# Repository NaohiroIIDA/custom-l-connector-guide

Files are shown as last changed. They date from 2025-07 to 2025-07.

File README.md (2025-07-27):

# ホットボンド成形によるL字コネクタ加工ガイド

このリポジトリは、汎用のコネクタをホットボンドと金型でL字加工する手順と、そのためのアルミ金型を低価格で外注する方法をまとめたものです。

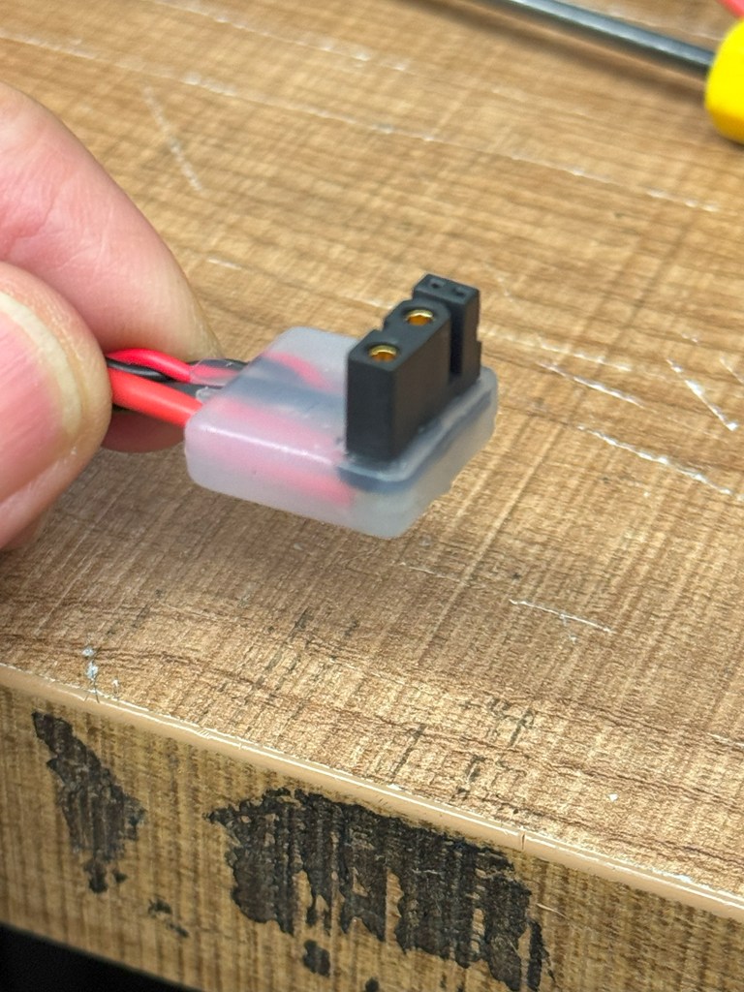
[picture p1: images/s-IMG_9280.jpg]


## 🔧 目的

ロボットや電子回路のケーブル配線において、コネクタの向きをモータに沿わせたい場面は多々あります。  
本ガイドでは、誰でも簡単に、安価に、L字のコネクタ加工ができるようにノウハウを共有します。

---

## 📦 内容一覧

- `mold-design/` : アルミ金型の設計図（PDF・CAD）
- `jlccnc-order-guide.md` : JLCCNCで金型を発注する方法
- `connector-molding.md` : 実際のL字加工手順
- `parts-list.md` : 使用部材・工具一覧
- `images/` : 各工程の写真・完成例

---

## 🌎 金型発注先について

金型は中国のCNC加工サービス「JLCCNC（[https://jlccnc.com](https://jlccnc.com)）」を利用しました。  
アルミ製の簡易金型で、1個あたり約\$38。発注から6日で到着しました。

詳細な発注手順は [`jlccnc-order-guide.md`](jlccnc-order-guide.md) をご覧ください。

---

## ✋ 注意事項

- 本ガイドはDIY用途を想定しています。高電圧・高周波用途のコネクタには使用しないでください。
- 加熱器具やホットボンド使用時は火傷にご注意ください。

---

## 📄 ライセンス

このリポジトリの内容は [CC BY 4.0](https://creativecommons.org/licenses/by/4.0/deed.ja) に基づき公開しています。

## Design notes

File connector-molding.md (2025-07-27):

# L字コネクタ加工の手順（ホットボンド成形）

このファイルでは、JLCCNCで製作したアルミ金型を用いて、USBやピンヘッダなどの汎用コネクタをホットボンド樹脂でL字に成形する手順を解説します。

---

## 🧰 使用するもの

| 品名 | 備考 |
|---|---|
| アルミ金型（上下2ピース） | JLCCNCで発注 |
| 加工したいコネクタ | 例：XT30(2+2),USBなど |
| ホットボンドガン（スティック） | 高温タイプ推奨 |
| ネジ・クランプ等 | 金型固定用 |
| 耐熱手袋 | 安全対策に |
| ニッパー、カッターなど | 成形後のバリ処理用 |

---

## 🛠 加工手順

### 1. 金型の準備
- 金型をきれいに拭き取り、内部に残ったホコリや異物を取り除く
- 必要に応じて、シリコンスプレーなどで軽く離型処理を行う

### 2. コネクタの設置
- コネクタの端子やケーブルを曲げ、L字の形に合わせて金型内に設置する
- 端子がずれないように注意し、必要なら仮止めテープなどを使用する

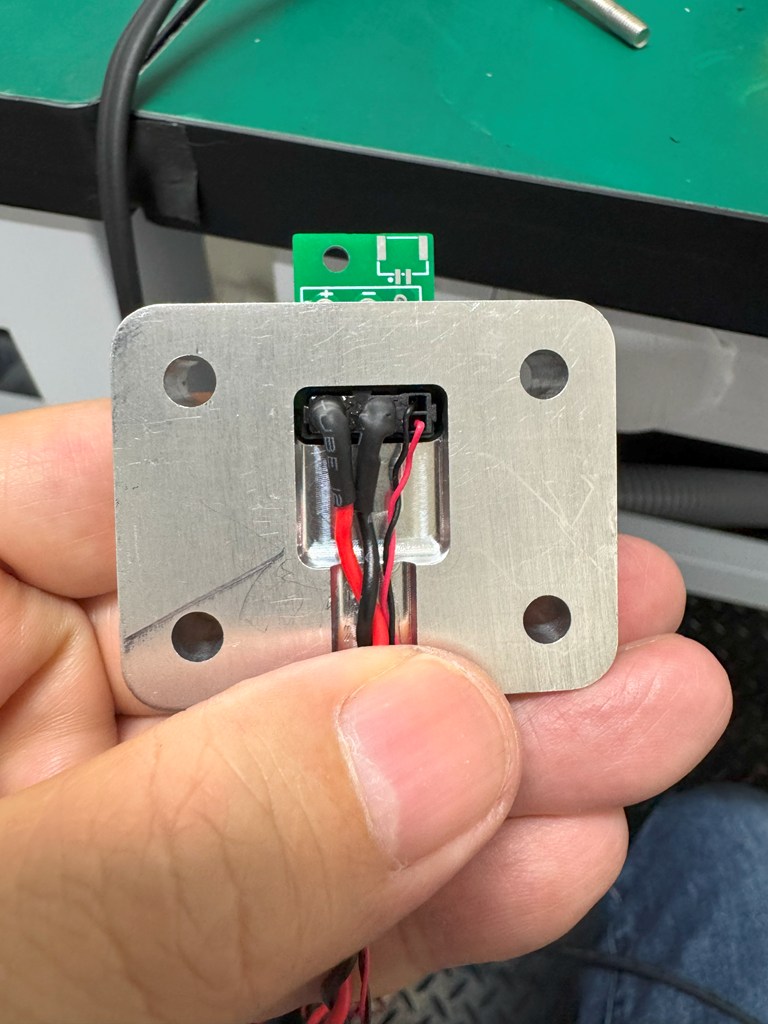
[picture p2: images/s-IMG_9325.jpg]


### 3. 金型の固定
- 上下の金型を合わせ、ネジやクランプでしっかりと固定する

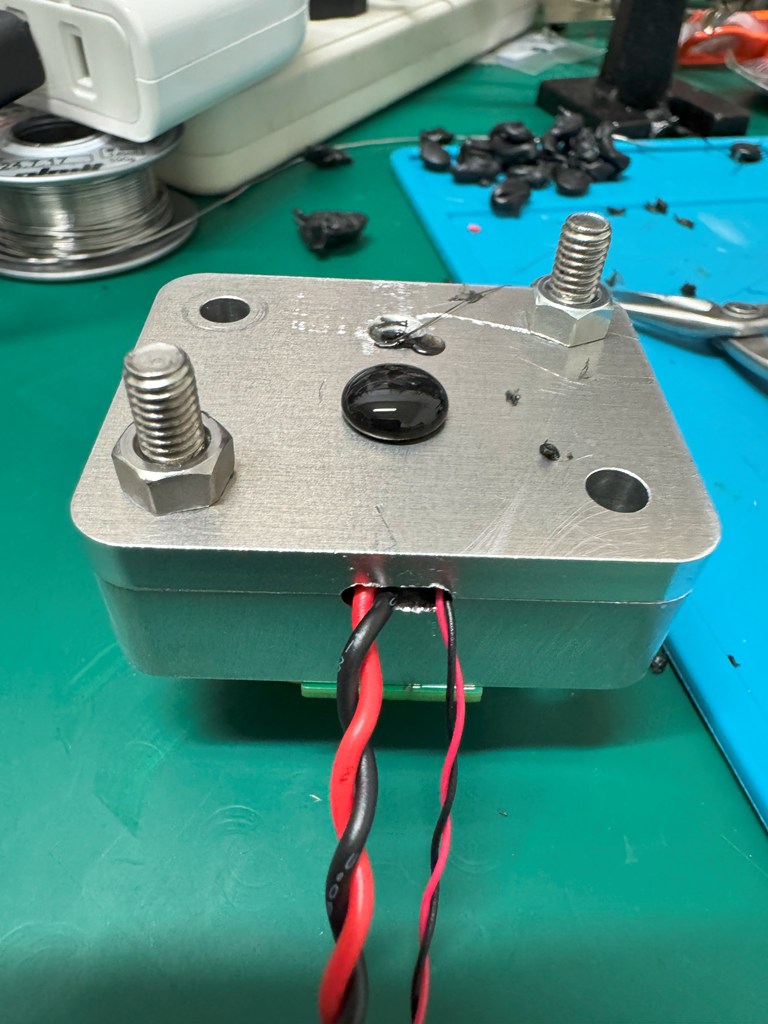
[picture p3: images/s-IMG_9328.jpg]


### 4. ホットボンド注入
- ホットボンドを加熱して十分に溶かす
- 金型の注入口から慎重にホットボンドを注入する  
  ※スティックが固いうちは圧力がかかりにくいので、ゆっくり押し出す
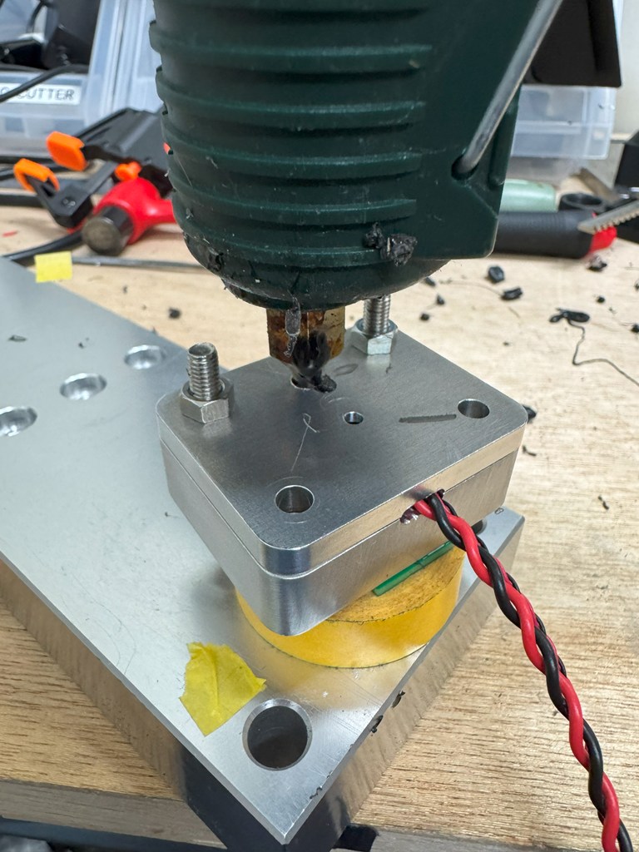
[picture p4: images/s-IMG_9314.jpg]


### 5. 冷却
- 2～3分放置して、完全に冷めるまで待つ  
  （必要に応じて金属製のプレートなどで外部から冷却してもOK）

### 6. 金型の取り外し
- 固定を外し、金型を慎重に分離する
- 成形されたL字コネクタを取り出す
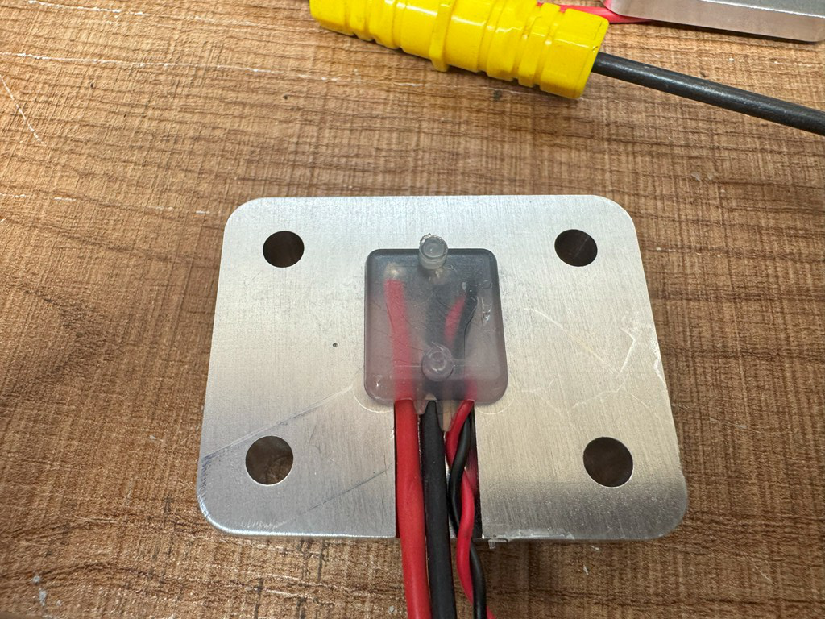
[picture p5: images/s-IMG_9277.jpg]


### 7. バリ取り・仕上げ
- ニッパーやカッターでバリを除去
- 必要に応じてヤスリで軽く整える


---

## ✅ 完成例

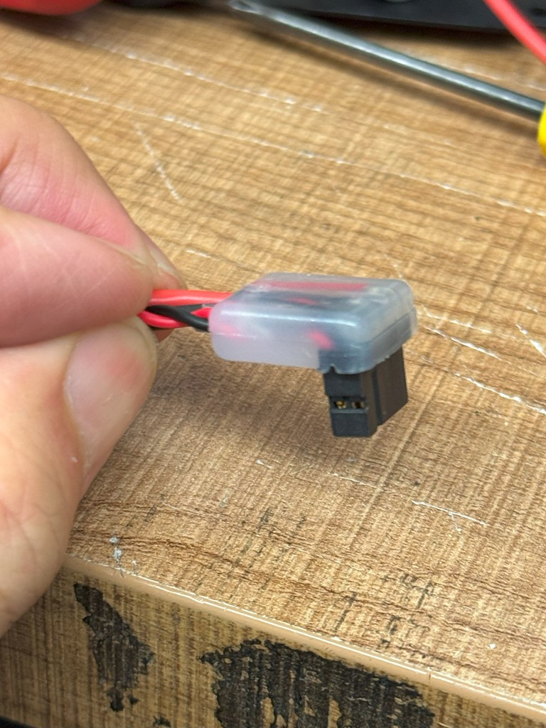
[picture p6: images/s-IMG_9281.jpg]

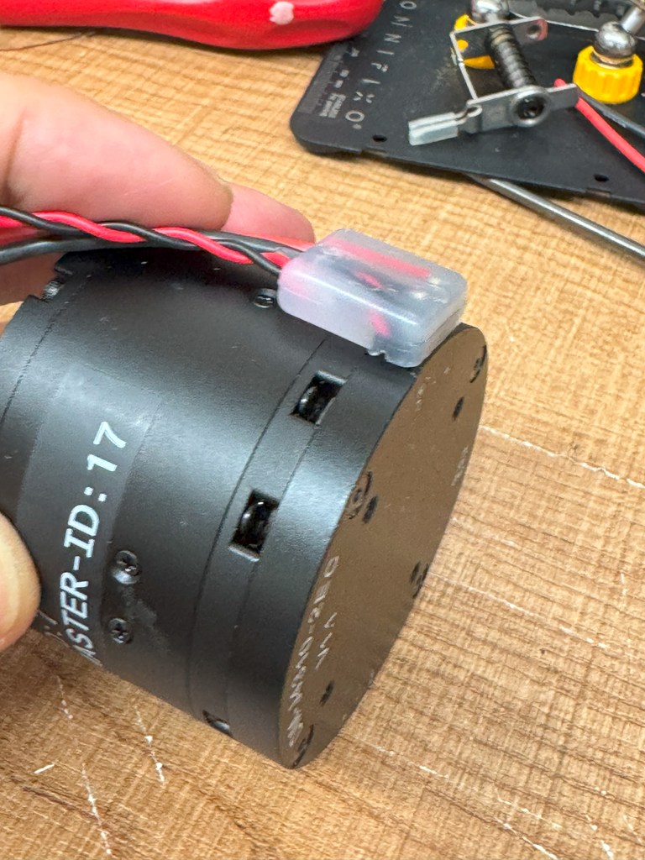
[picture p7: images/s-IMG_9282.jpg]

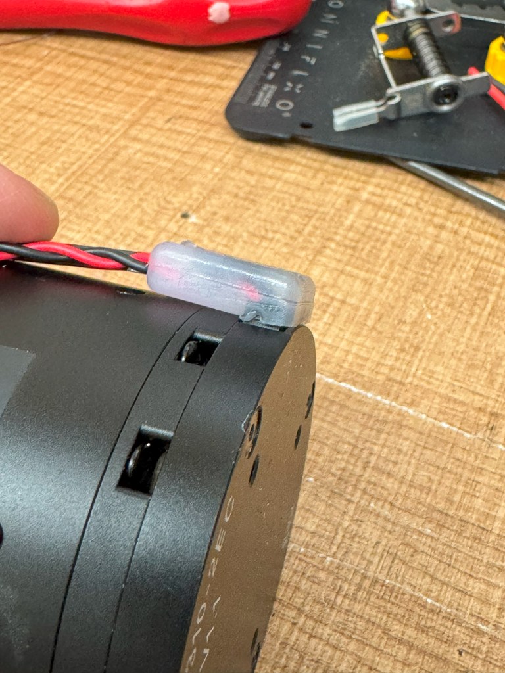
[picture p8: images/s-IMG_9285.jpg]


---

## 💡 コツと注意点

- ホットボンドは加熱しすぎないように（煙が出ると温度が高すぎ）
- コネクタの接点や金属部分にホットボンドが入り込まないよう注意
- ケーブルをあらかじめL字形にクセ付けしておくと作業が楽
- 初めての場合は不要な部品でテスト成形するのがおすすめ

---

## 📎 補足情報

- 使用した金型図面：[mold-design/l_shape_mold_v1.pdf](mold-design/l_shape_mold_v1.pdf)
- 金型の発注方法：[jlccnc-order-guide.md](jlccnc-order-guide.md)

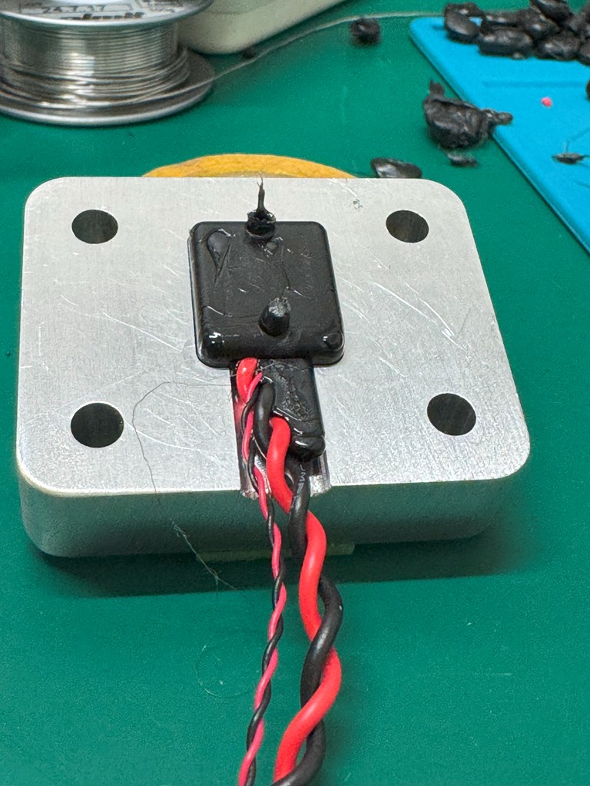
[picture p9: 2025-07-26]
images/s-IMG_9329.jpg

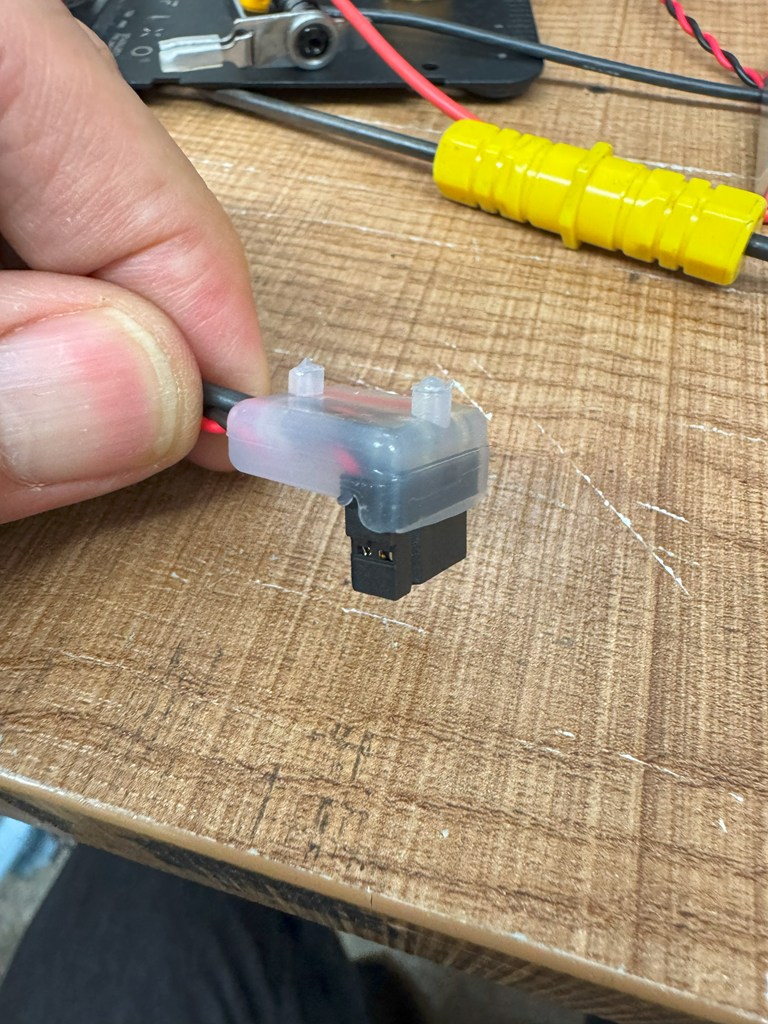
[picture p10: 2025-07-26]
images/s-IMG_9278.jpg

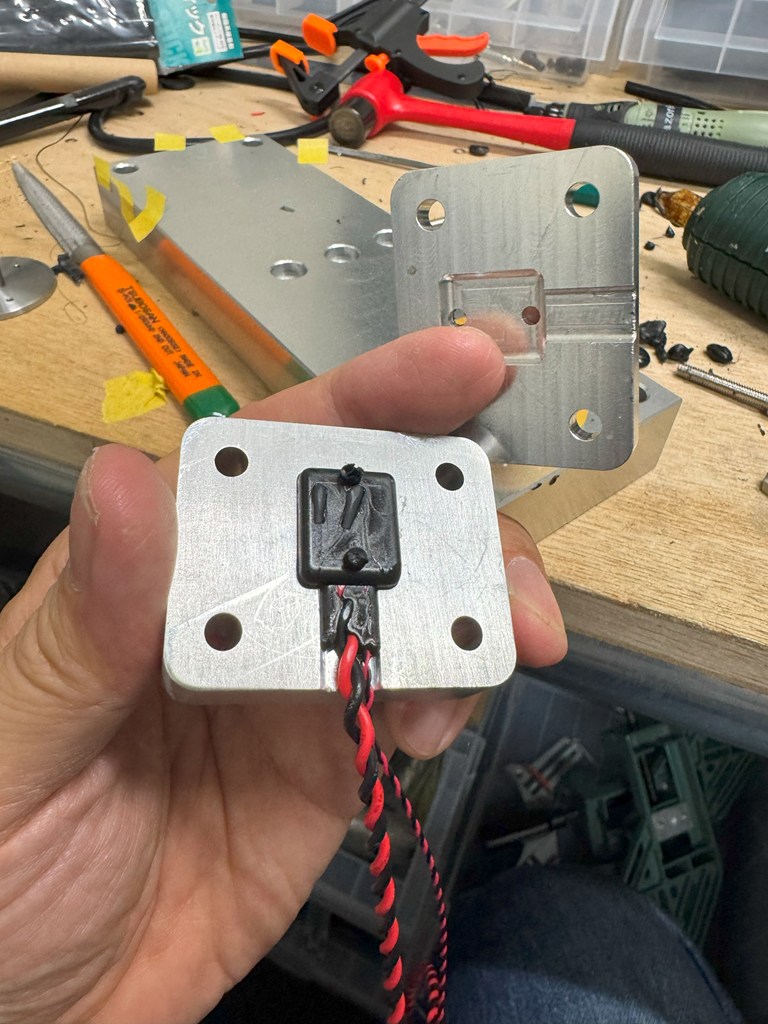
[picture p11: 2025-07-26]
images/s-IMG_9313.jpg

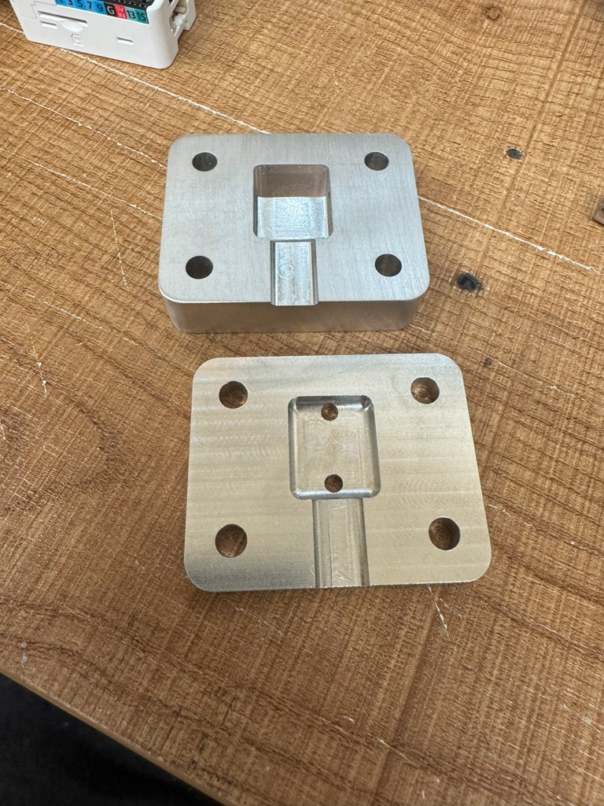
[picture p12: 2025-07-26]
images/s-IMG_9274.jpg

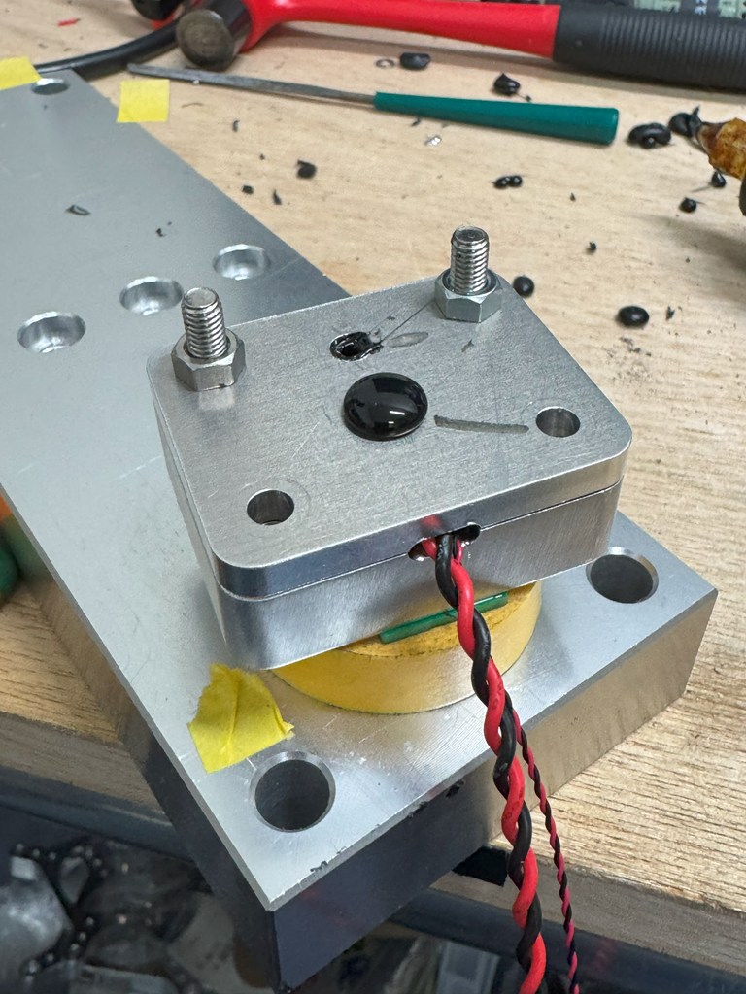
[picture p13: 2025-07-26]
images/s-IMG_9312.jpg

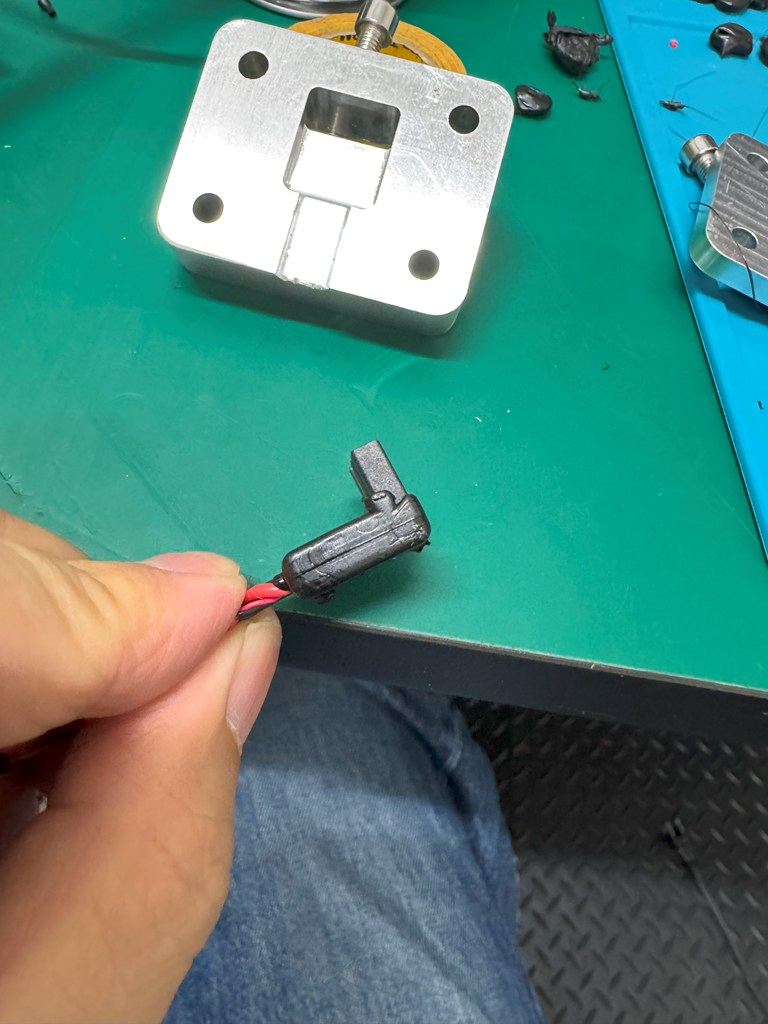
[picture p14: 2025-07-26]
images/s-IMG_9330.jpg

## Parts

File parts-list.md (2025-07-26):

# 使用部材・工具リスト

このページでは、ホットボンド成形によるL字コネクタ加工に使用した部材・工具の一覧をまとめています。  
リンクや品番は一例として参考にしてください。

---

## 🧩 使用部材（消耗品）

| 名称 | 用途 | 備考 |
|---|---|---|
| ホットボンドスティック（高温タイプ） | 成形用樹脂 | 直径7mmまたは11mm、黒色もアリ |
| 加工対象のコネクタ | 成形対象 | USB-A、USB-C、JST、2.54mmヘッダ等 |
| シリコンスプレー（離型剤） | 金型への密着防止 | 必須ではないが仕上げ向上 |
| テフロンテープ（必要に応じて） | コネクタ保護 | 金属ピンへの樹脂付着を防止 |

---

## 🔧 使用工具

| 名称 | 用途 | 備考 |
|---|---|---|
| ホットボンドガン | 成形材料の加熱・注入 | 高温型・精密ノズル推奨 |
| アルミ金型（上下2ピース） | 成形型 | JLCCNCでCNC加工したもの |
| ダミーコネクタ付き基板 | 成形型 | 対象となるデバイスのダミー |
| クランプまたはボルト・ナット | 金型固定 | 樹脂注入時のズレ防止用 |
| 耐熱手袋 | 安全対策 | 高温作業時の火傷防止 |
| カッター・ニッパー | バリ取り | 成形後の仕上げ作業 |
| マイナスドライバー | 型外し | 型を開ける際に使用 |

---

## 🧰 推奨する追加道具（任意）

| 名称 | 用途 |
|---|---|
| デジタル温度計 | ホットボンド温度確認 |
| ヒートガン | 軽い余熱、表面修正 |
| 万力（バイス） | 作業台固定用として便利 |

---

## 🛒 購入先の例

| 製品 | 購入先例 |
|---|---|
| ホットボンド・ガン | Amazon、モノタロウ、秋月電子など |
| コネクタ類 | 秋月電子、aitendo、LCSCなど |
| 金型用CNC加工 | [JLCCNC（https://jlccnc.com）](https://jlccnc.com) |

---

## 📎 関連ドキュメント

- [金型の発注手順](jlccnc-order-guide.md)
- [成形手順の詳細](connector-molding.md)

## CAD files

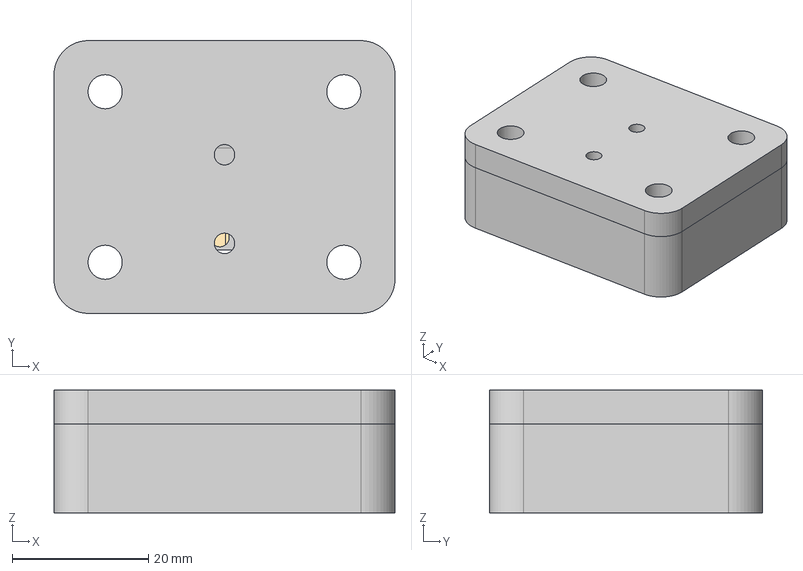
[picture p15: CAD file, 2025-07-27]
ホットボンド金型 v7.step
50.0 x 40.0 x 18.0 mm
XT30(2+2)
UP_KANA
Down_KANA

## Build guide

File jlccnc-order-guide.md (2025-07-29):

# JLCCNCでL字コネクタ用アルミ金型を発注する方法

このページでは、CNC加工サービス「[JLCCNC](https://jlccnc.com)」を使って、ホットボンド成形用のL字コネクタ金型を外注する方法を説明します。

## 📝 概要

- 加工内容：L字ホットボンド用金型（アルミ製・2ピース構造）
- 素材：アルミ（AL6061推奨）
- サイズ：約30mm × 30mm × 10mm 程度
- 価格：約 \$38（送料別）
- 発注日：6月10日
- 到着日：6月16日（6日で到着）

---

## 🔧 事前準備

### 必要なもの
- 加工用のデータ（.STEP)
- JLCCNCのアカウント（登録無料）
- クレジットカードまたはPayPal

---

## 🛒 発注手順

1. **[JLCCNC公式サイト](https://jlccnc.com) にアクセス**
2. トップページの「**CNC Machining**」の方の　**Quote Now** ボタンをクリック  
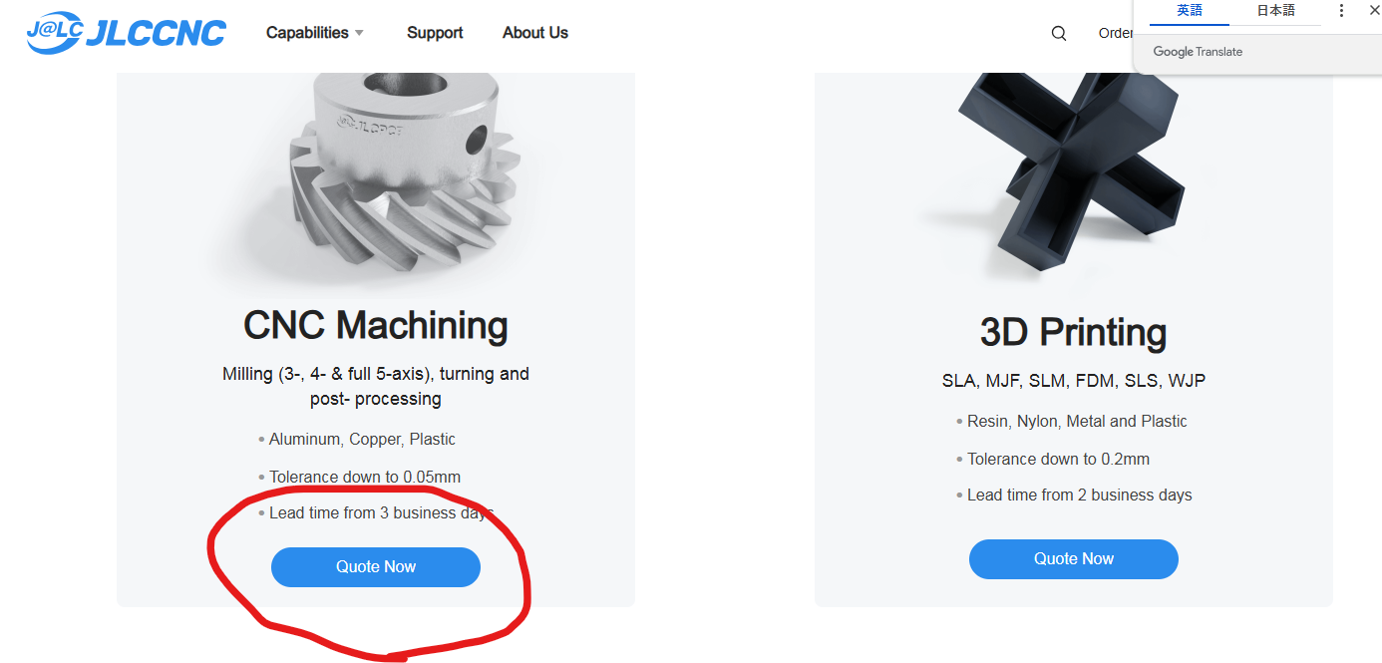
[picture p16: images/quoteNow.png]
   
3. 加工データ（例：`l_shape_mold_v1.pdf`）をUpload 3D modelsへアップロード
4. アップロード後、「**材料（Material,Type of Aluminum）**」「**表面処理（Surface Finish）**」などを選択  
   - Material：Aluminum 6061
   - Surface :No (Finish：As machined) 今回、特に表面処理などは行いませんでした。
5. 加工数量（例：1個）を指定
6. 商品説明　(Product Desc) を選択
   -出荷の際の申告名称らしい。『Irregular shape Category -> Other -> "mold"』と記入しています。
7. 画面右側にTotal Priceが表示されているので確認する。Build timeを選ぶ。今回はStandardを選択。 
   
10. 見積価格に問題なければそのまま「**Submit Order**」をクリックし、支払いを完了

---

## 📦 到着時の様子
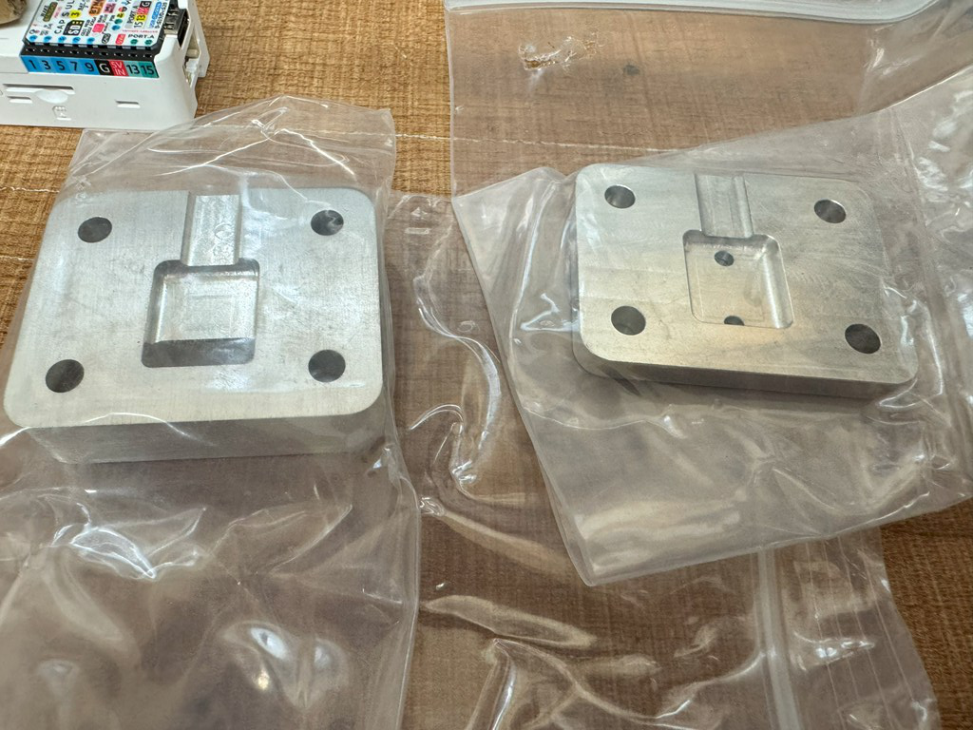
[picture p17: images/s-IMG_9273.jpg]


しっかりとアルミで加工された金型が、緩衝材と一緒に丁寧に梱包されて届きます。

---

## 💡 注意点・コツ

- データはSTEPが最もスムーズです
- 小物金型の場合、送料込みでも\$50以内に収まることが多いです

---

## 🔗 参考資料

- 発注に使用したデータ：ホットボンド金型 v7.step
- JLCCNC公式サイト：[https://jlccnc.com](https://jlccnc.com)

---

## ❓ Q&A

**Q: 日本語のやり取りはできますか？**  
A: 基本は英語対応ですが、Google翻訳などを使えば問題なく進行可能です。

**Q: 他の金型も頼めますか？**  
A: あくまで簡易的なものだと思います。鋭角な角や狭い空間などは加工できないとしてリジェクトされる場合があります。お知らせを見てデータを修正しましょう。
